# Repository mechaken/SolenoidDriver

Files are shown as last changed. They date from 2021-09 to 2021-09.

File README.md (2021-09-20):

# SolenoidDriver

### 表
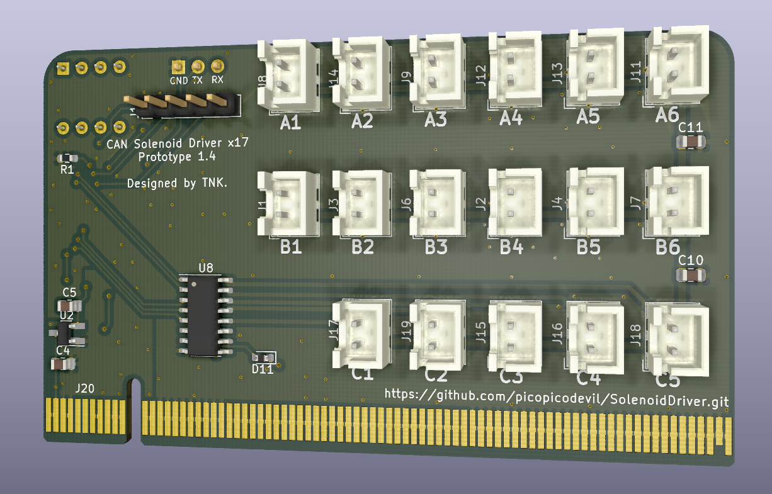
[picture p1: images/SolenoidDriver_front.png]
SolenoidDriver front

### 裏
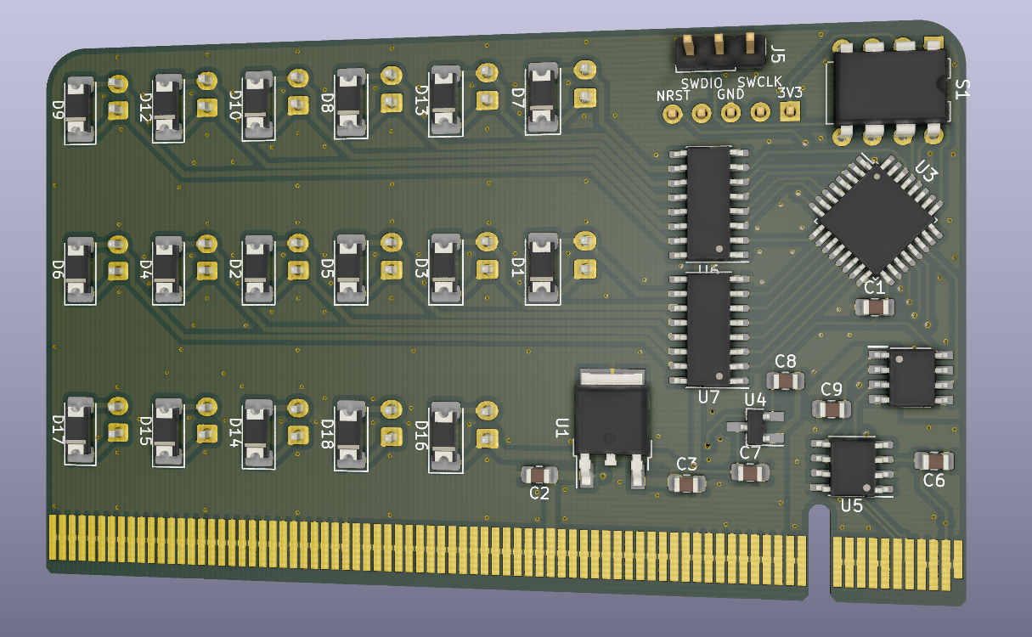
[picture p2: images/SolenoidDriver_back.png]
SolenoidDriver back

## 概要
独自にピン定義したPCIeを使ったソレノイド駆動回路です。

最大17個のソレノイドを接続と駆動ができます。(17個も駆動させない場合は、A-Cのうち使用する行に接続されているダーリントントランジスタやその他部品のみ実装し、動作させることも可能です。)

作成しているモータードライバ([CAN-H-Bridge_Solo_MD](https://github.com/picopicodevil/CAN_H-Bridge_Solo_MD))とほぼ同じ大きさなので、同一のマザーボードの中にモータードライバと本基板を入れることが可能です。

## 機能
- CAN通信を用いたソレノイドの制御
- DIPスイッチを利用して、同じプログラムで同一CANバスに最大4つ搭載可能
- ディジタルアイソレータを用いた制御-駆動電源の分離

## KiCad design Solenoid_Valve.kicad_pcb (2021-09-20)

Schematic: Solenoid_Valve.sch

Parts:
C1, C3, C6, C9: 0.1u; C_0805_2012Metric_Pad1.18x1.45mm_HandSolder
C2: 0.33u; C_0805_2012Metric_Pad1.18x1.45mm_HandSolder
C4, C7: 1.0u; C_0805_2012Metric_Pad1.18x1.45mm_HandSolder
C5, C8: 2.2u; C_0805_2012Metric_Pad1.18x1.45mm_HandSolder
C10, C11: 10u; C_0805_2012Metric_Pad1.18x1.45mm_HandSolder
D1, D2, D3, D4, D5, D6, D7, D8, D9, D10, D12, D13, D14, D15, D16, D17, D18: D; D_2010_5025Metric_Pad1.52x2.65mm_HandSolder
D11: D_Schottky; D_0603_1608Metric_Pad1.05x0.95mm_HandSolder
IC1: Si8621AB-B-ISR; SOIC127P600X175-8N; Mouser Part Number 634-SI8621AB-B-ISR
J1, J2, J3, J4, J6, J7, J8, J9, J11, J12, J13, J14, J15, J16, J17, J18, J19: Conn_01x02; JST_XH_B2B-XH-A_1x02_P2.50mm_Vertical
J5: Conn_01x03; PinHeader_1x03_P2.54mm_Vertical
J10: Conn_01x05; PinHeader_1x05_P2.54mm_Vertical
J20: Bus_mechaken_PCIexpress_x16_164_Position; BUS_mechaken_PCIexpress_x16
R1: 10K; R_0603_1608Metric_Pad0.98x0.95mm_HandSolder
S1: IKD0403101; DIP-8_W7.62mm
U1: NJM7812; TO-252-2
U2, U4: AP2210N-3.3TRG1; SOT-23_Handsoldering
U3: STM32F303K8Tx; LQFP-32_7x7mm_P0.8mm
U5: MCP2562-E-SN; SOIC-8_3.9x4.9mm_P1.27mm
U6, U7, U8: ULN2003; SOIC-16_3.9x9.9mm_P1.27mm

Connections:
3.3V: C1.2, C8.1, D11.2 (A), IC1.8 (VDD2), J10.1, S1.1, S1.2, U3.1 (VDD), U3.5 (VDDA), U3.17 (VDD), U4.2 (VO)
+3V3: C5.2, C9.2, IC1.1 (VDD1), U2.2 (VO), U5.5 (Vio)
+5V: C4.1, C6.2, J20.A1 (+5V), J20.B1 (+5V), U2.3 (VI), U5.3 (VDD)
+12V: C3.1, C7.1, C10.1, C11.1, D1.1 (K), D2.1 (K), D3.1 (K), D4.1 (K), D5.1 (K), D6.1 (K), D7.1 (K), D8.1 (K), D9.1 (K), D10.1 (K), D12.1 (K), D13.1 (K), D14.1 (K), D15.1 (K), D16.1 (K), D17.1 (K), D18.1 (K), J1.1, J2.1, J3.1, J4.1, J6.1, J7.1, J8.1, J9.1, J11.1, J12.1, J13.1, J14.1, J15.1, J16.1, J17.1, J18.1, J19.1, U1.3 (OUT), U4.3 (VI), U6.9, U7.9, U8.9
/BOOT: R1.1, U3.31 (BOOT0)
/SWCLK: J10.2, U3.24 (PA14)
/SWDIO: J10.4, U3.23 (PA13)
CAN+: J20.A4 (CANH), U5.7 (CANH)
CAN-: J20.A3 (CANL), U5.6 (CANL)
CAN_RD: IC1.7 (B1), U3.21 (PA11)
CAN_RXD: IC1.2 (A1), U5.4 (RXD)
CAN_TD: IC1.6 (B2), U3.22 (PA12)
CAN_TXD: IC1.3 (A2), U5.1 (TXD)
DIP_SW_1: S1.8, U3.28 (PB5)
DIP_SW_2: S1.7, U3.29 (PB6)
GND: C4.2, C5.1, C6.1, C9.1, IC1.4 (GND1), J20.A2 (GND), J20.B2 (GND), U2.1 (GND), U5.2 (VSS), U5.8 (STBY)
GNDPWR: C1.1, C2.2, C3.2, C7.2, C8.2, C10.2, C11.2, IC1.5 (GND2), J5.1, J10.3, J20.A8 (GNDPWR), J20.A10 (GNDPWR), J20.B8 (GNDPWR), J20.B10 (GNDPWR), R1.2, U1.2 (GND), U3.16 (VSS), U3.32 (VSS), U4.1 (GND), U6.8, U7.8, U8.8
IC_A1: U3.30 (PB7), U6.7
IC_A2: U3.2 (PF0), U6.6
IC_A3: U3.3 (PF1), U6.5
IC_A4: U3.6 (PA0), U6.4
IC_A5: U3.7 (PA1), U6.3
IC_A6: U3.9 (PA3), U6.2
IC_B1: U3.10 (PA4), U7.7
IC_B2: U3.11 (PA5), U7.6
IC_B3: U3.12 (PA6), U7.5
IC_B4: U3.13 (PA7), U7.4
IC_B5: U3.14 (PB0), U7.3
IC_B6: U3.15 (PB1), U7.2
IC_C1: U3.20 (PA10), U8.5
IC_C2: U3.19 (PA9), U8.4
IC_C3: U3.18 (PA8), U8.3
IC_C4: U3.26 (PB3), U8.2
IC_C5: U3.27 (PB4), U8.1
NRST: J10.5, U3.4 (NRST)
Solenoid_A1: D7.2 (A), J8.2, U6.10
Solenoid_A2: D13.2 (A), J14.2, U6.11
Solenoid_A3: D8.2 (A), J9.2, U6.12
Solenoid_A4: D10.2 (A), J12.2, U6.13
Solenoid_A5: D12.2 (A), J13.2, U6.14
Solenoid_A6: D9.2 (A), J11.2, U6.15
Solenoid_B1: D1.2 (A), J1.2, U7.10
Solenoid_B2: D3.2 (A), J3.2, U7.11
Solenoid_B3: D5.2 (A), J6.2, U7.12
Solenoid_B4: D2.2 (A), J2.2, U7.13
Solenoid_B5: D4.2 (A), J4.2, U7.14
Solenoid_B6: D6.2 (A), J7.2, U7.15
Solenoid_C1: D16.2 (A), J17.2, U8.12
Solenoid_C2: D18.2 (A), J19.2, U8.13
Solenoid_C3: D14.2 (A), J15.2, U8.14
Solenoid_C4: D15.2 (A), J16.2, U8.15
Solenoid_C5: D17.2 (A), J18.2, U8.16
VCC: C2.1, D11.1 (K), J20.A9 (VCC), U1.1 (IN)
VCP_RX: J5.3, U3.25 (PA15)
VCP_TX: J5.2, U3.8 (PA2)

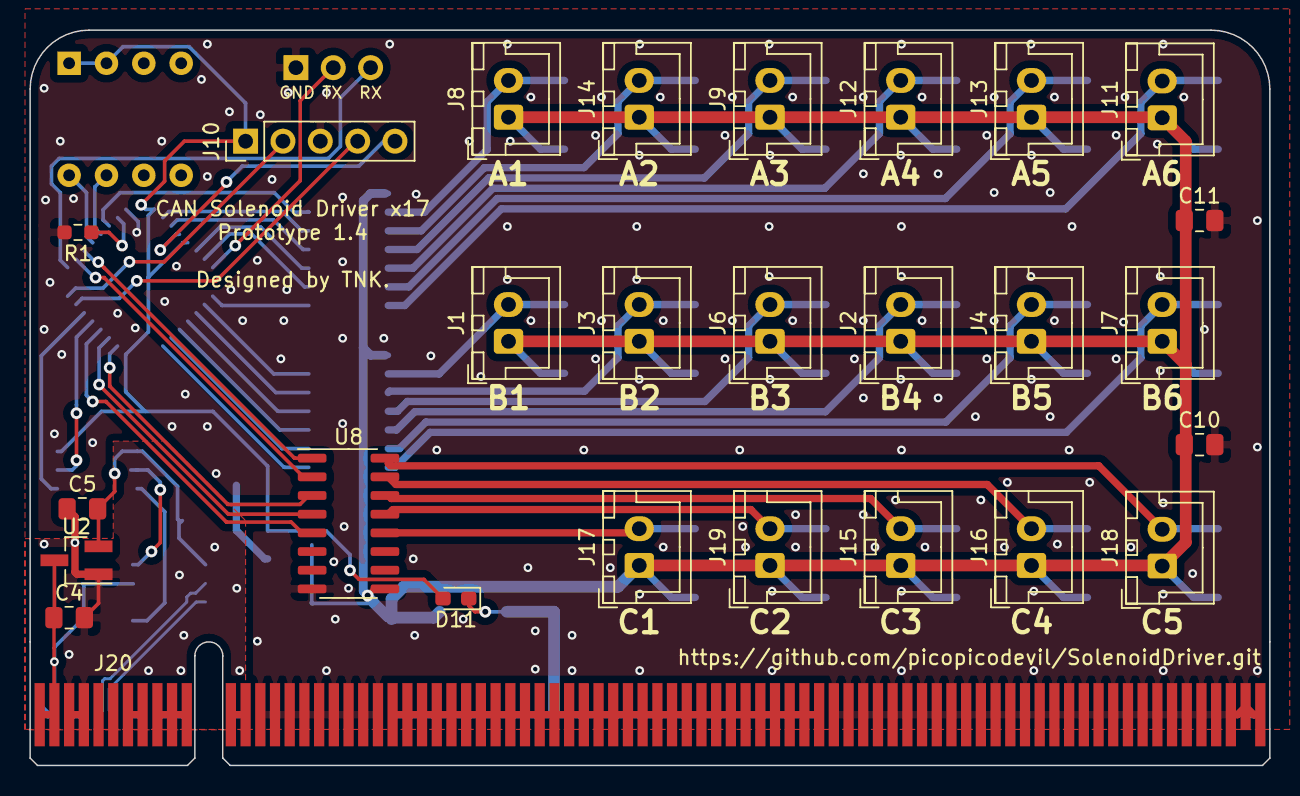
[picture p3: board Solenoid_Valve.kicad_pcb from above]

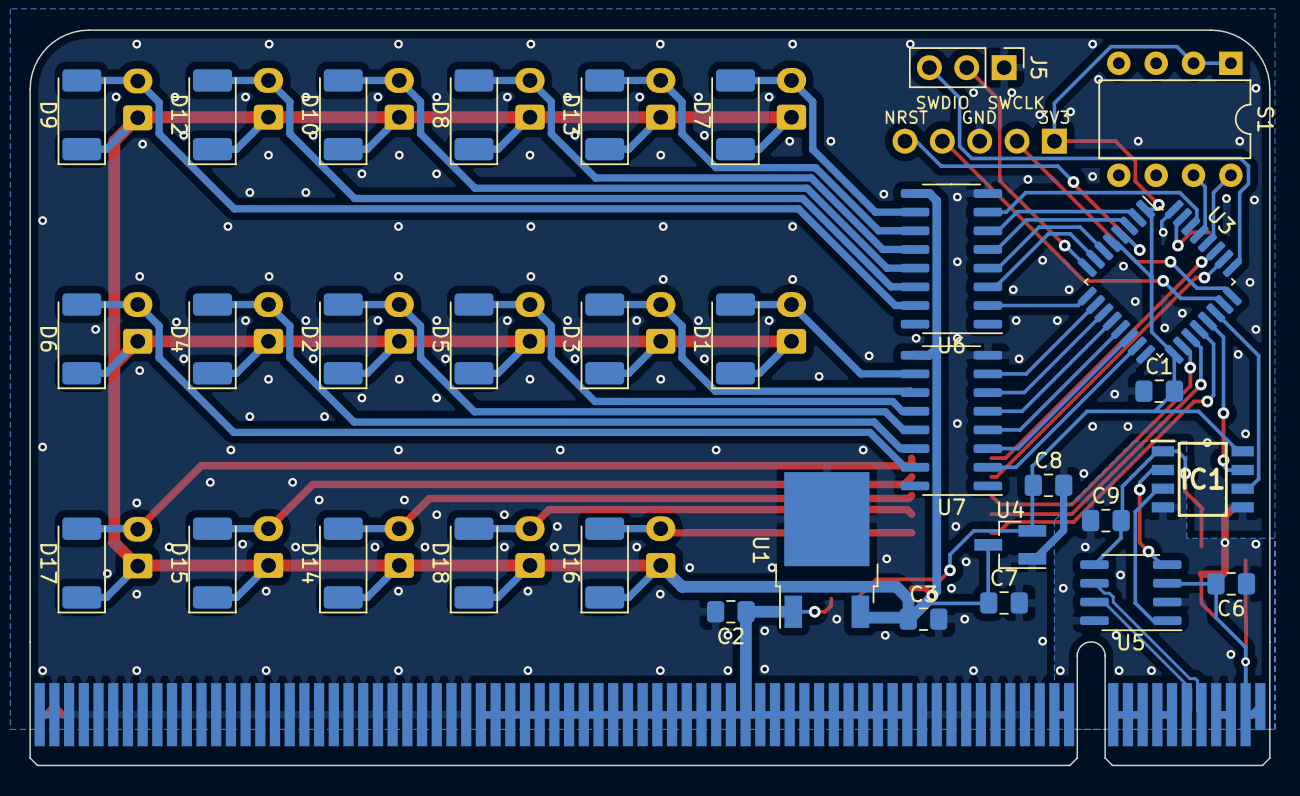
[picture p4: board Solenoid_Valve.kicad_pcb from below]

Board: 2 copper layers, 84.3 x 50.0 mm, 60 parts (33 on the bottom side), 55 nets.

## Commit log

2019-12-24 change
    Remove NRST SW
    clean
    [Solenoid_Valve-fin.kicad_pcb, Solenoid_Valve.kicad_pcb, Solenoid_Valve.sch]
2020-01-19 fix
    ST-LINK部分の配線を修正
    [Solenoid_Valve.kicad_pcb]
2020-02-21 fix
    BOOT0の配線を修正
    [Solenoid_Valve.kicad_pcb, Solenoid_Valve.sch]
2020-03-04 change
    フットプリントを手はんだ用に変更
    レギュレーター保護用のダイオードを追加
    [Solenoid_Valve.kicad_pcb, Solenoid_Valve.sch]
2020-03-04 Release
    ガーバーファイルを出力
    [Solenoid_Valve-fin-B_Cu.gbl, Solenoid_Valve-fin-B_Cu.gbr, Solenoid_Valve-fin-B_Mask.gbr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]
2020-06-21 Release
    Prototype-1.3をリリース
    [Solenoid_Valve-fin-B_Cu.gbl, Solenoid_Valve-fin-B_Cu.gbr, Solenoid_Valve-fin-B_Mask.gbr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]
2020-06-21 .gitignore is now working
    [Solenoid_Valve-fin-B_Cu.gbl, Solenoid_Valve-fin-B_Cu.gbr, Solenoid_Valve-fin-B_Mask.gbr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]
2020-11-03 Update: フットプリントライブラリの変更
    [Solenoid_Valve.kicad_pcb, Solenoid_Valve.sch]
2020-11-06 Fix: Symbol & Footprint Library
    [Solenoid_Valve.kicad_pcb, Solenoid_Valve.sch]
2020-11-07 Delete: ガーバーファイルを削除
    [Solenoid_Valve-fin-B_Cu.gbl, Solenoid_Valve-fin-B_Cu.gbr, Solenoid_Valve-fin-B_Mask.gbr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]
2020-11-07 Delete: 余分なファイルを削除
2020-11-07 Delete: pcb-bak
2020-11-07 Delete: ガーバーファイル
    [Solenoid_Valve-fin-B_Cu.gbl, Solenoid_Valve-fin-B_Mask.gbs, Solenoid_Valve-fin-B_SilkS.gbo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]
2020-11-21 Update: ダーリントントランジスタアレイをULN2003に変更
    [Solenoid_Valve.kicad_pcb, Solenoid_Valve.sch]
2021-09-20 Remove: 発注用ファイルを削除
    [Solenoid_Valve-fin.kicad_pcb]
2021-09-20 Update: IC1の3Dモデルを設定
    [Solenoid_Valve.kicad_pcb]
2021-09-20 Update: READMEを加筆
2021-09-20 Update: KiCadのバージョンが変更
    [Solenoid_Valve.kicad_pcb]
